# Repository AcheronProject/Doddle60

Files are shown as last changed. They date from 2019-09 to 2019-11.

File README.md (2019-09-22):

# Acheron ISO60-SM-S-STM32-MX-TH-WI (Codename "Doddle60")

Acheron Logo

See [this page](https://gondolindrim.github.io/AcheronDocs/doddle60/intro.html) for the Doddle60PCB documentation.

## Introduction

**Doddle**. *British slang for something easily accomplished*.

The Doddle60 is a 60% plain-style PCB aimed at ISO layout users. It features minimal layout support and no LED backlight support. It runs an STM32F072 processor, USBC connector, ESD protection on both data lines and metallic case discharge, as well as overvoltage and overcurrent protection.

The layout was cherry-picked and hinited to me by Jae of the TopClack channel, an avid ISO user brit.

## Supported layouts

Click [this link](http://www.keyboard-layout-editor.com/#/gists/dfb069e34f7b14d63b03305a79dfc469) for the KLE file for the Doddle60.

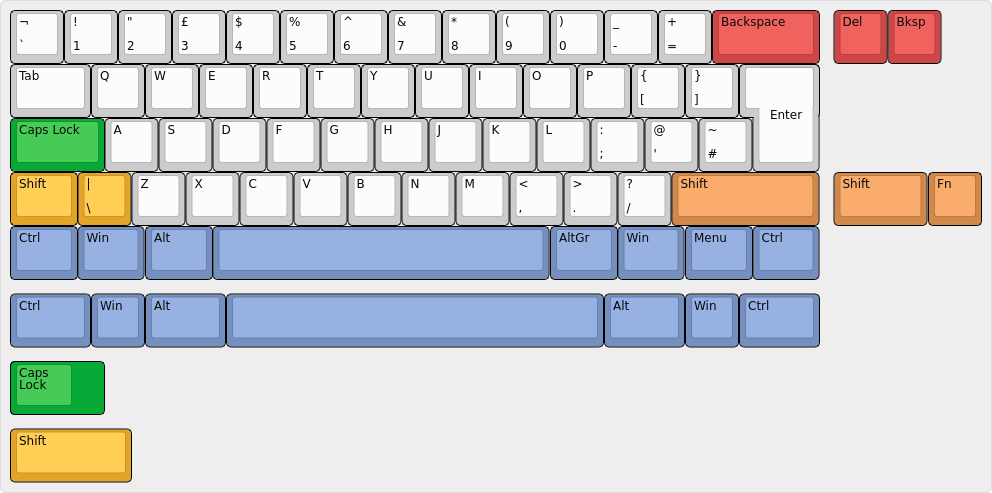
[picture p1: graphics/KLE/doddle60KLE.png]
Austin layouts


## Renders

Click at the images to zoom in.

Renders generated by the [tracespace.io](https://tracespace.io/view/) site.

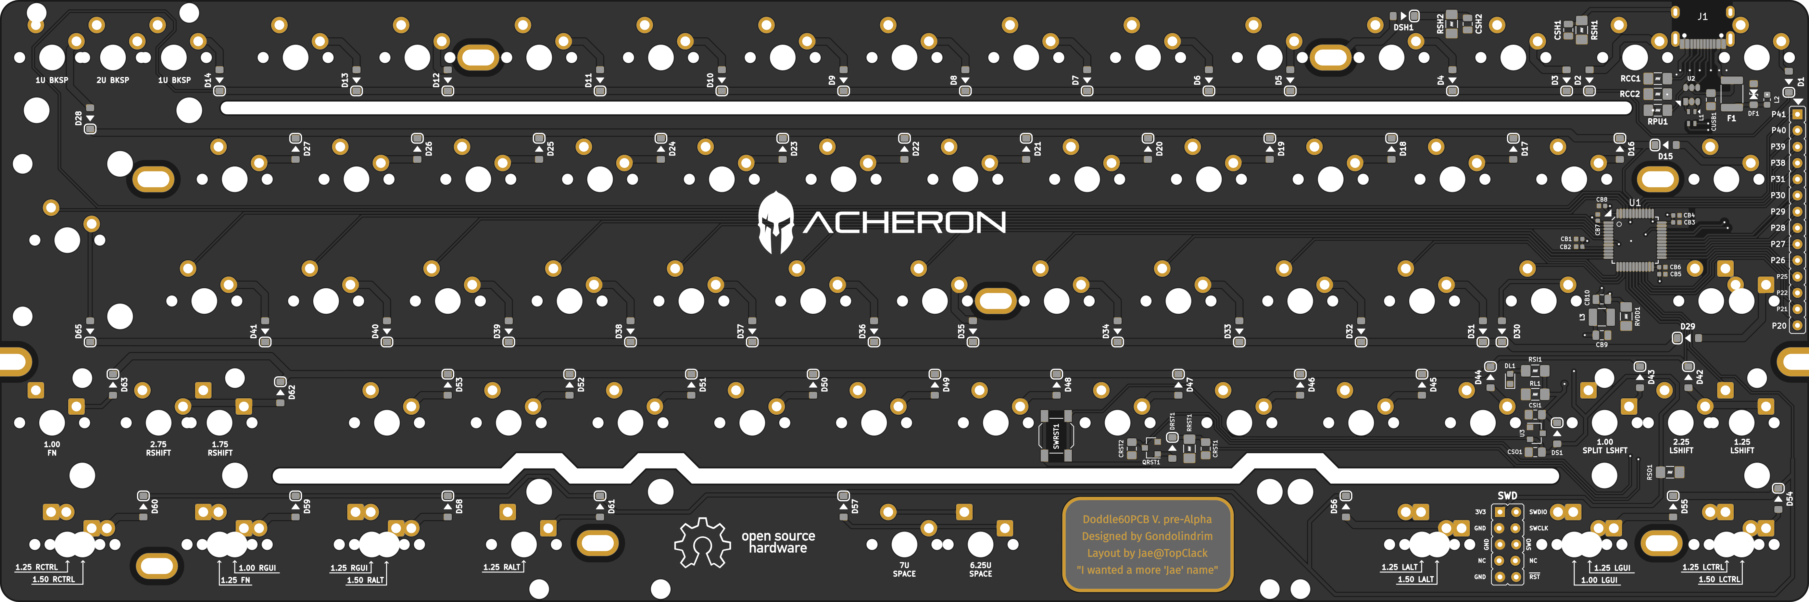
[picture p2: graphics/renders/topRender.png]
ArcticPCB Top Render


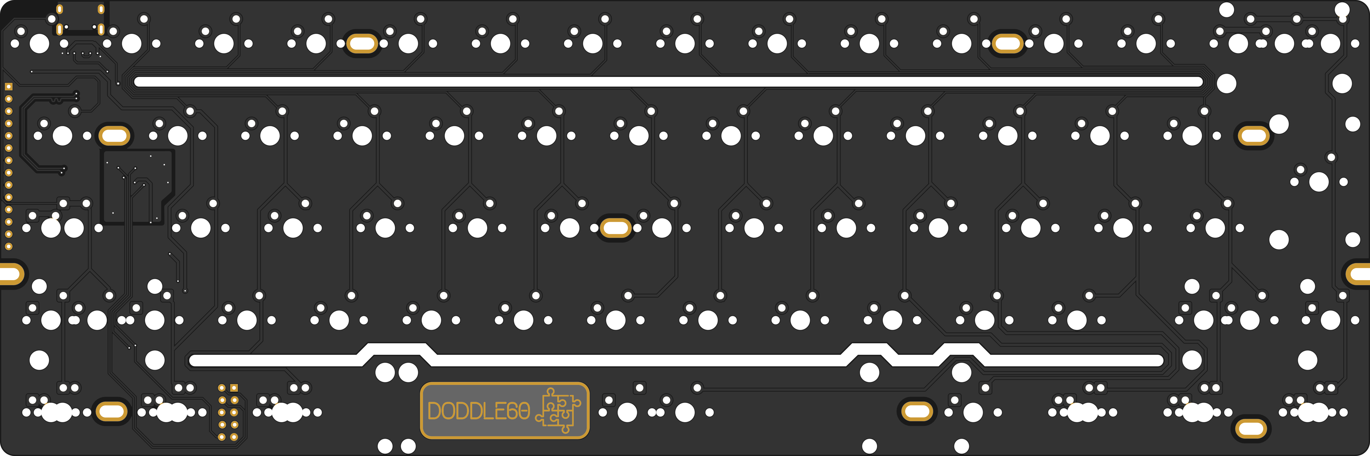
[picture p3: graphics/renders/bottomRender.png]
ArcticPCB Bottom Render


## Copyright notice

This project is released under the Acheron Open-Hardware License V1.1. For the license, please refer to the LICENCE.md file.

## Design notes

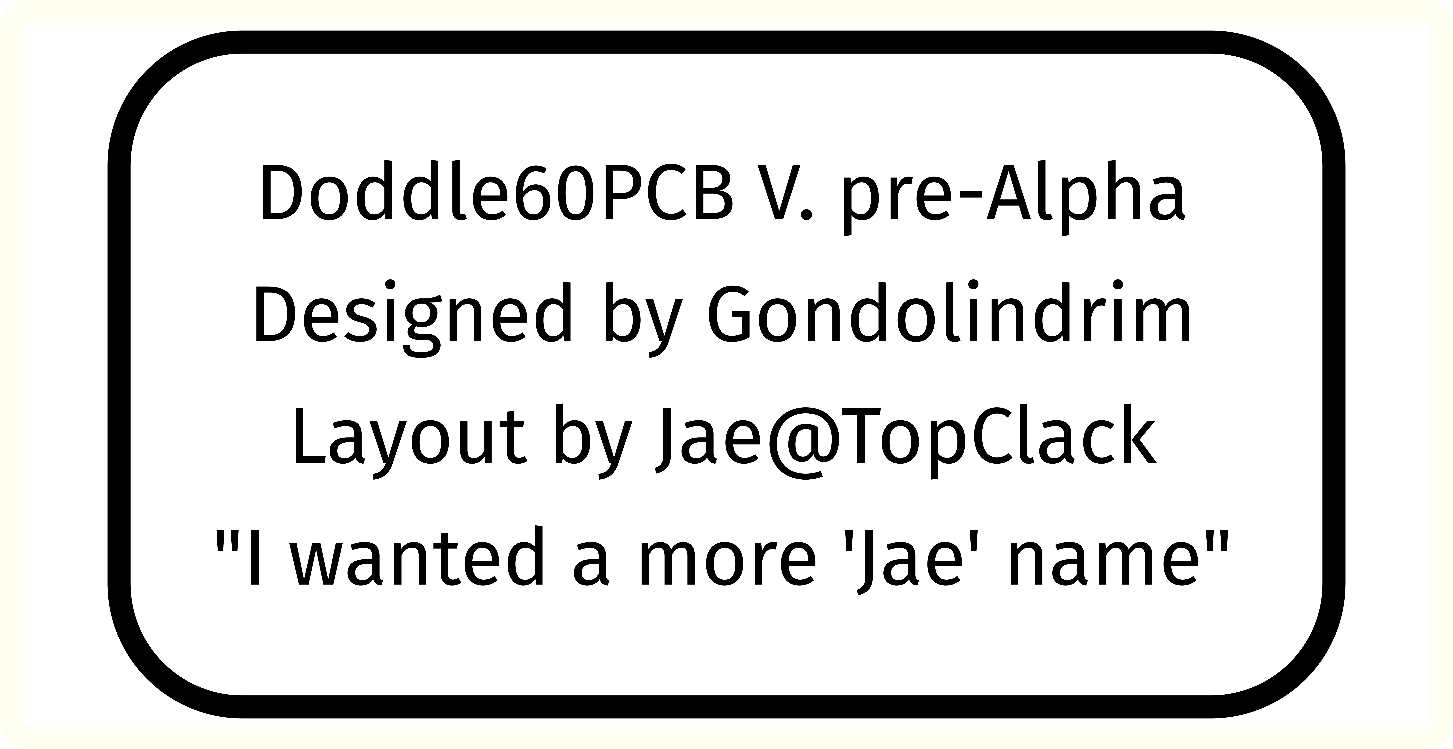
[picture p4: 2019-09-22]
graphics/doddle60Label/doddle60Label.png

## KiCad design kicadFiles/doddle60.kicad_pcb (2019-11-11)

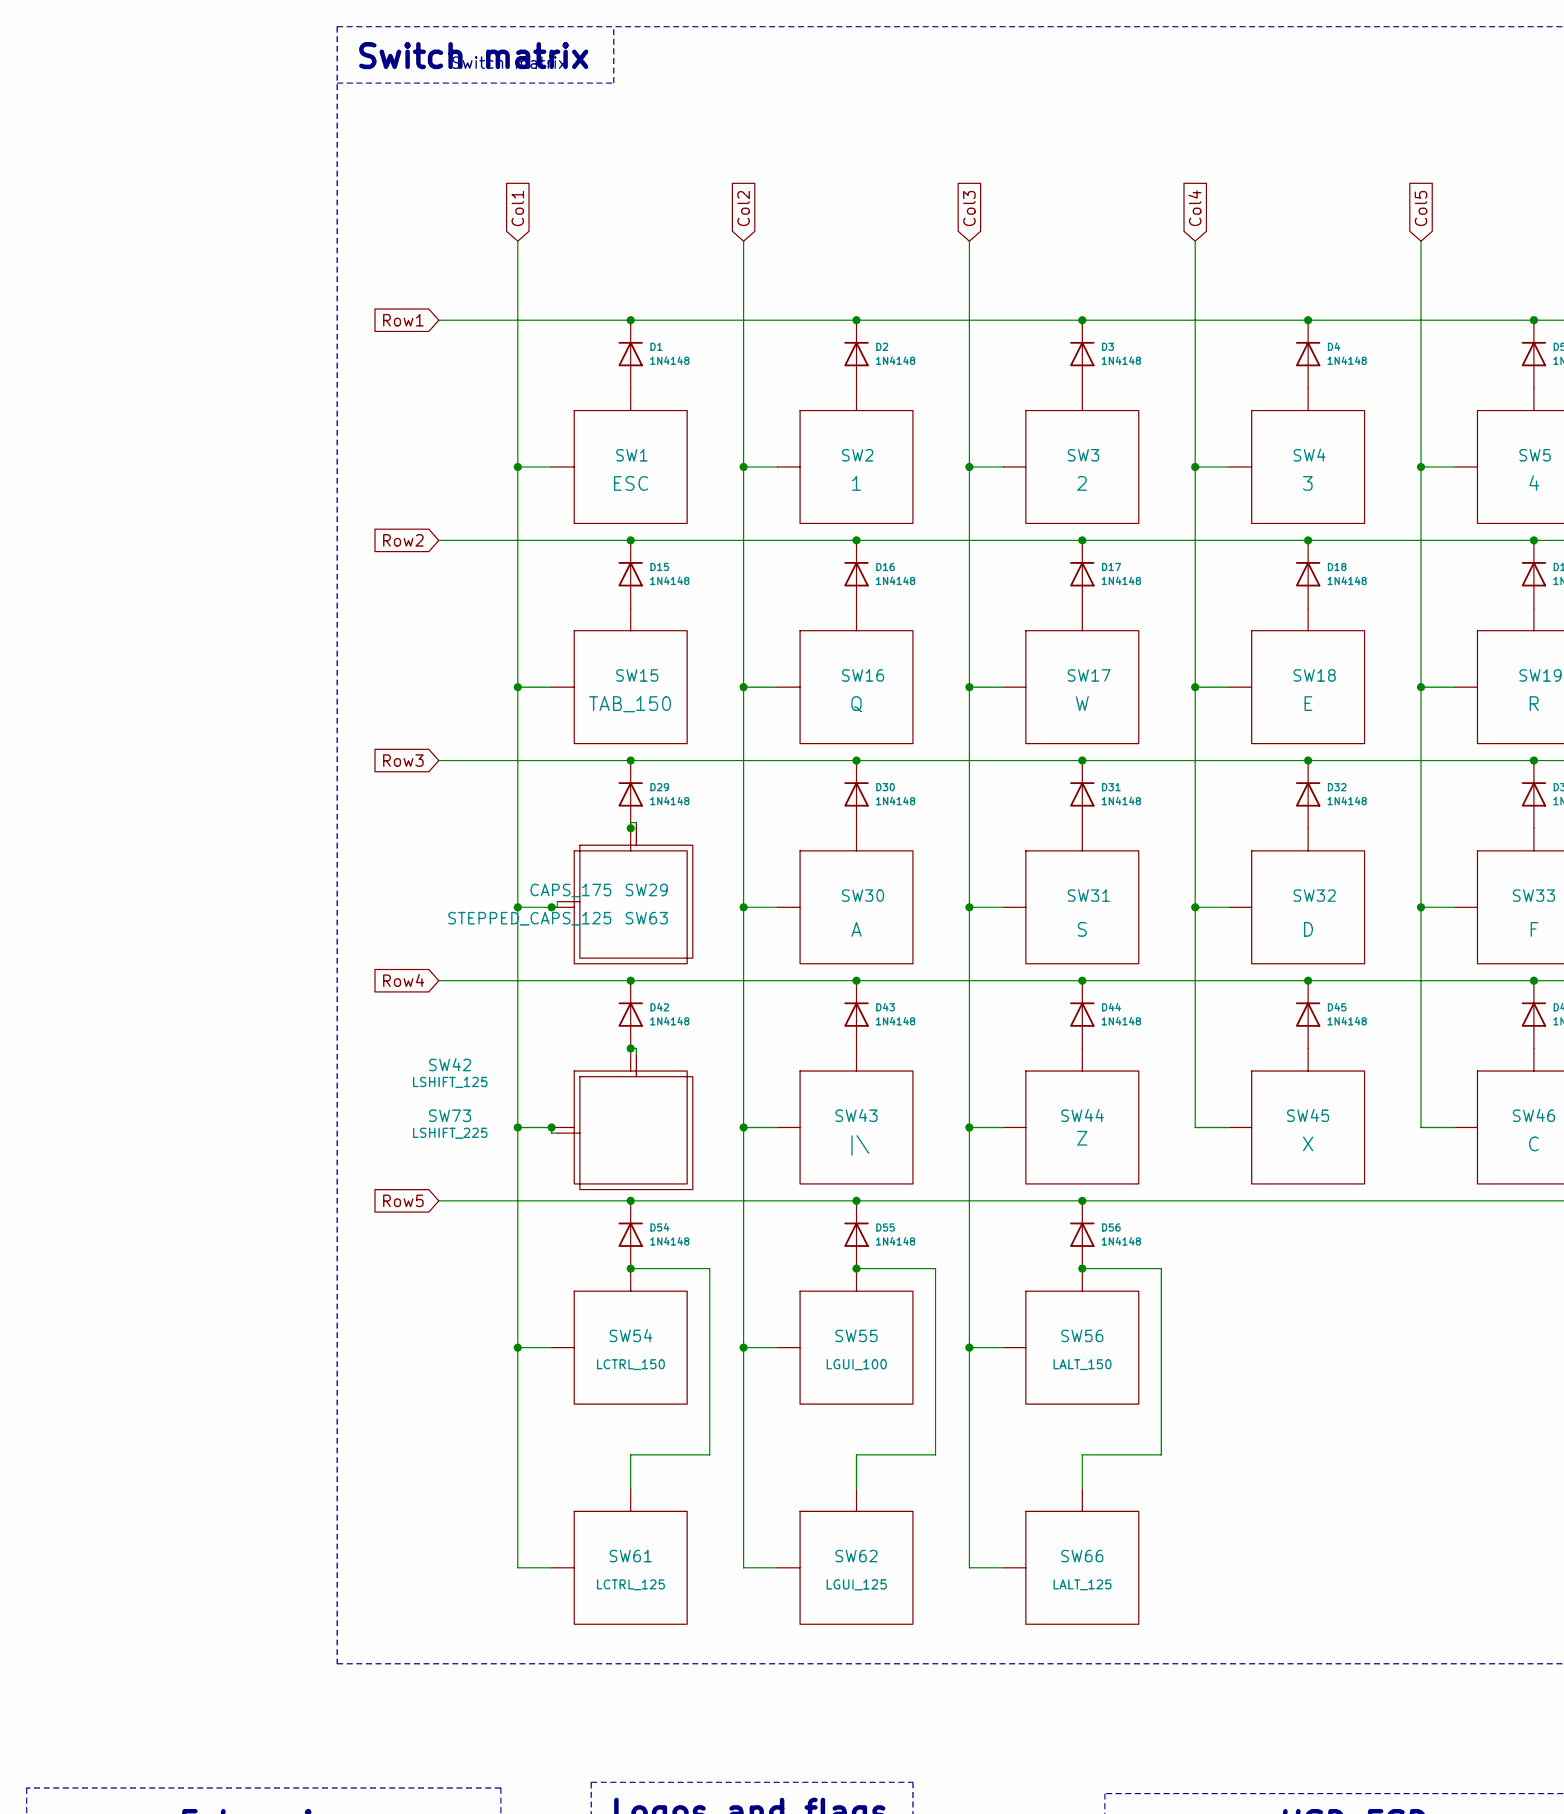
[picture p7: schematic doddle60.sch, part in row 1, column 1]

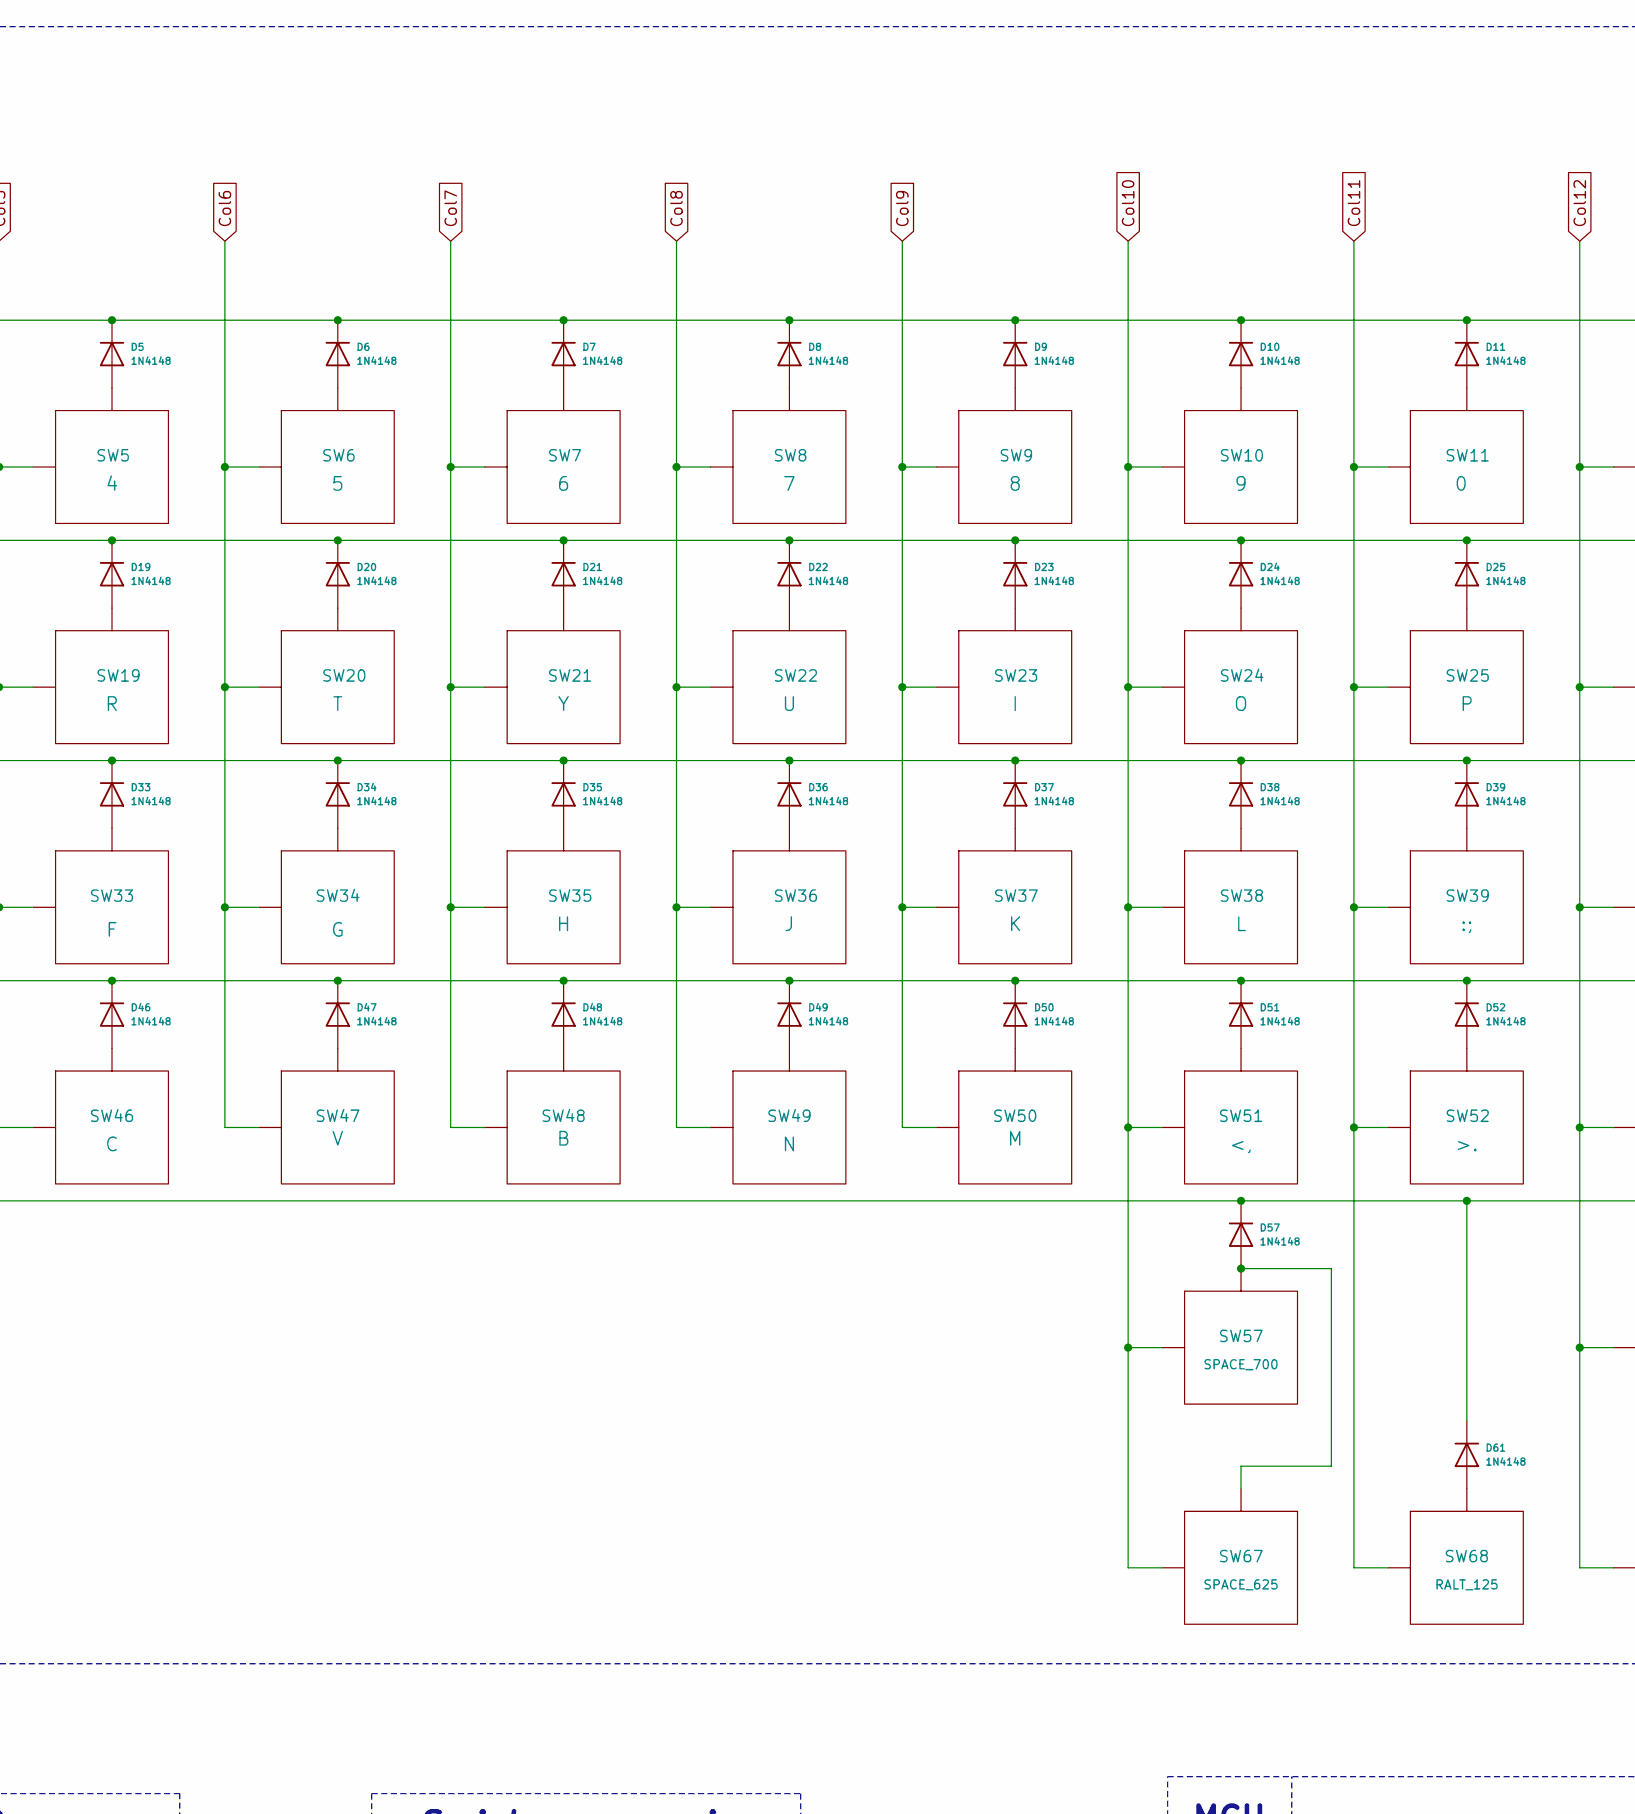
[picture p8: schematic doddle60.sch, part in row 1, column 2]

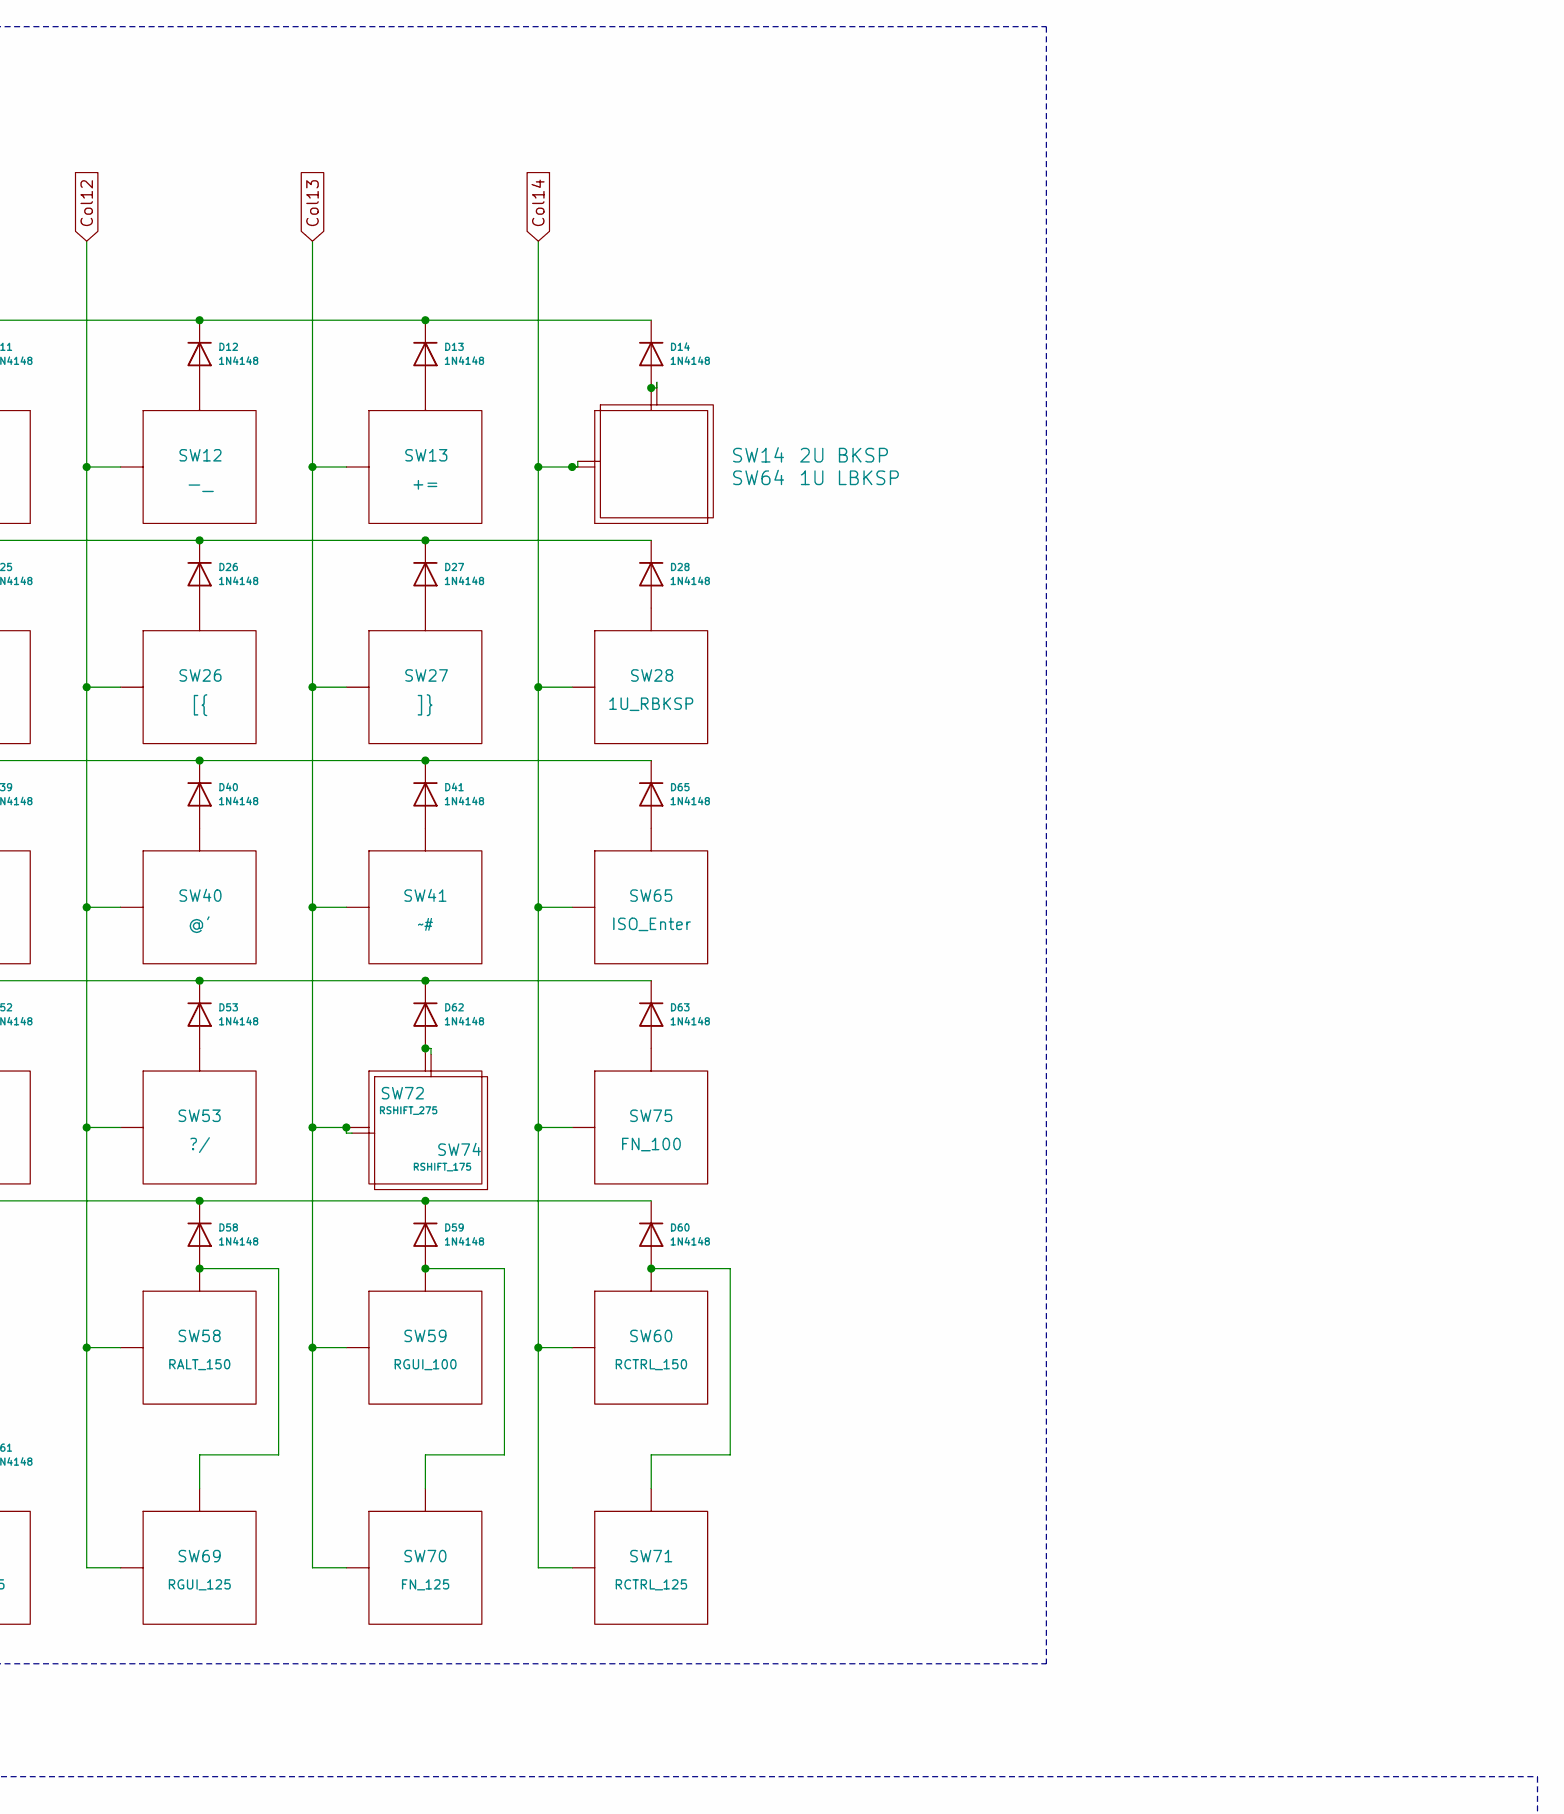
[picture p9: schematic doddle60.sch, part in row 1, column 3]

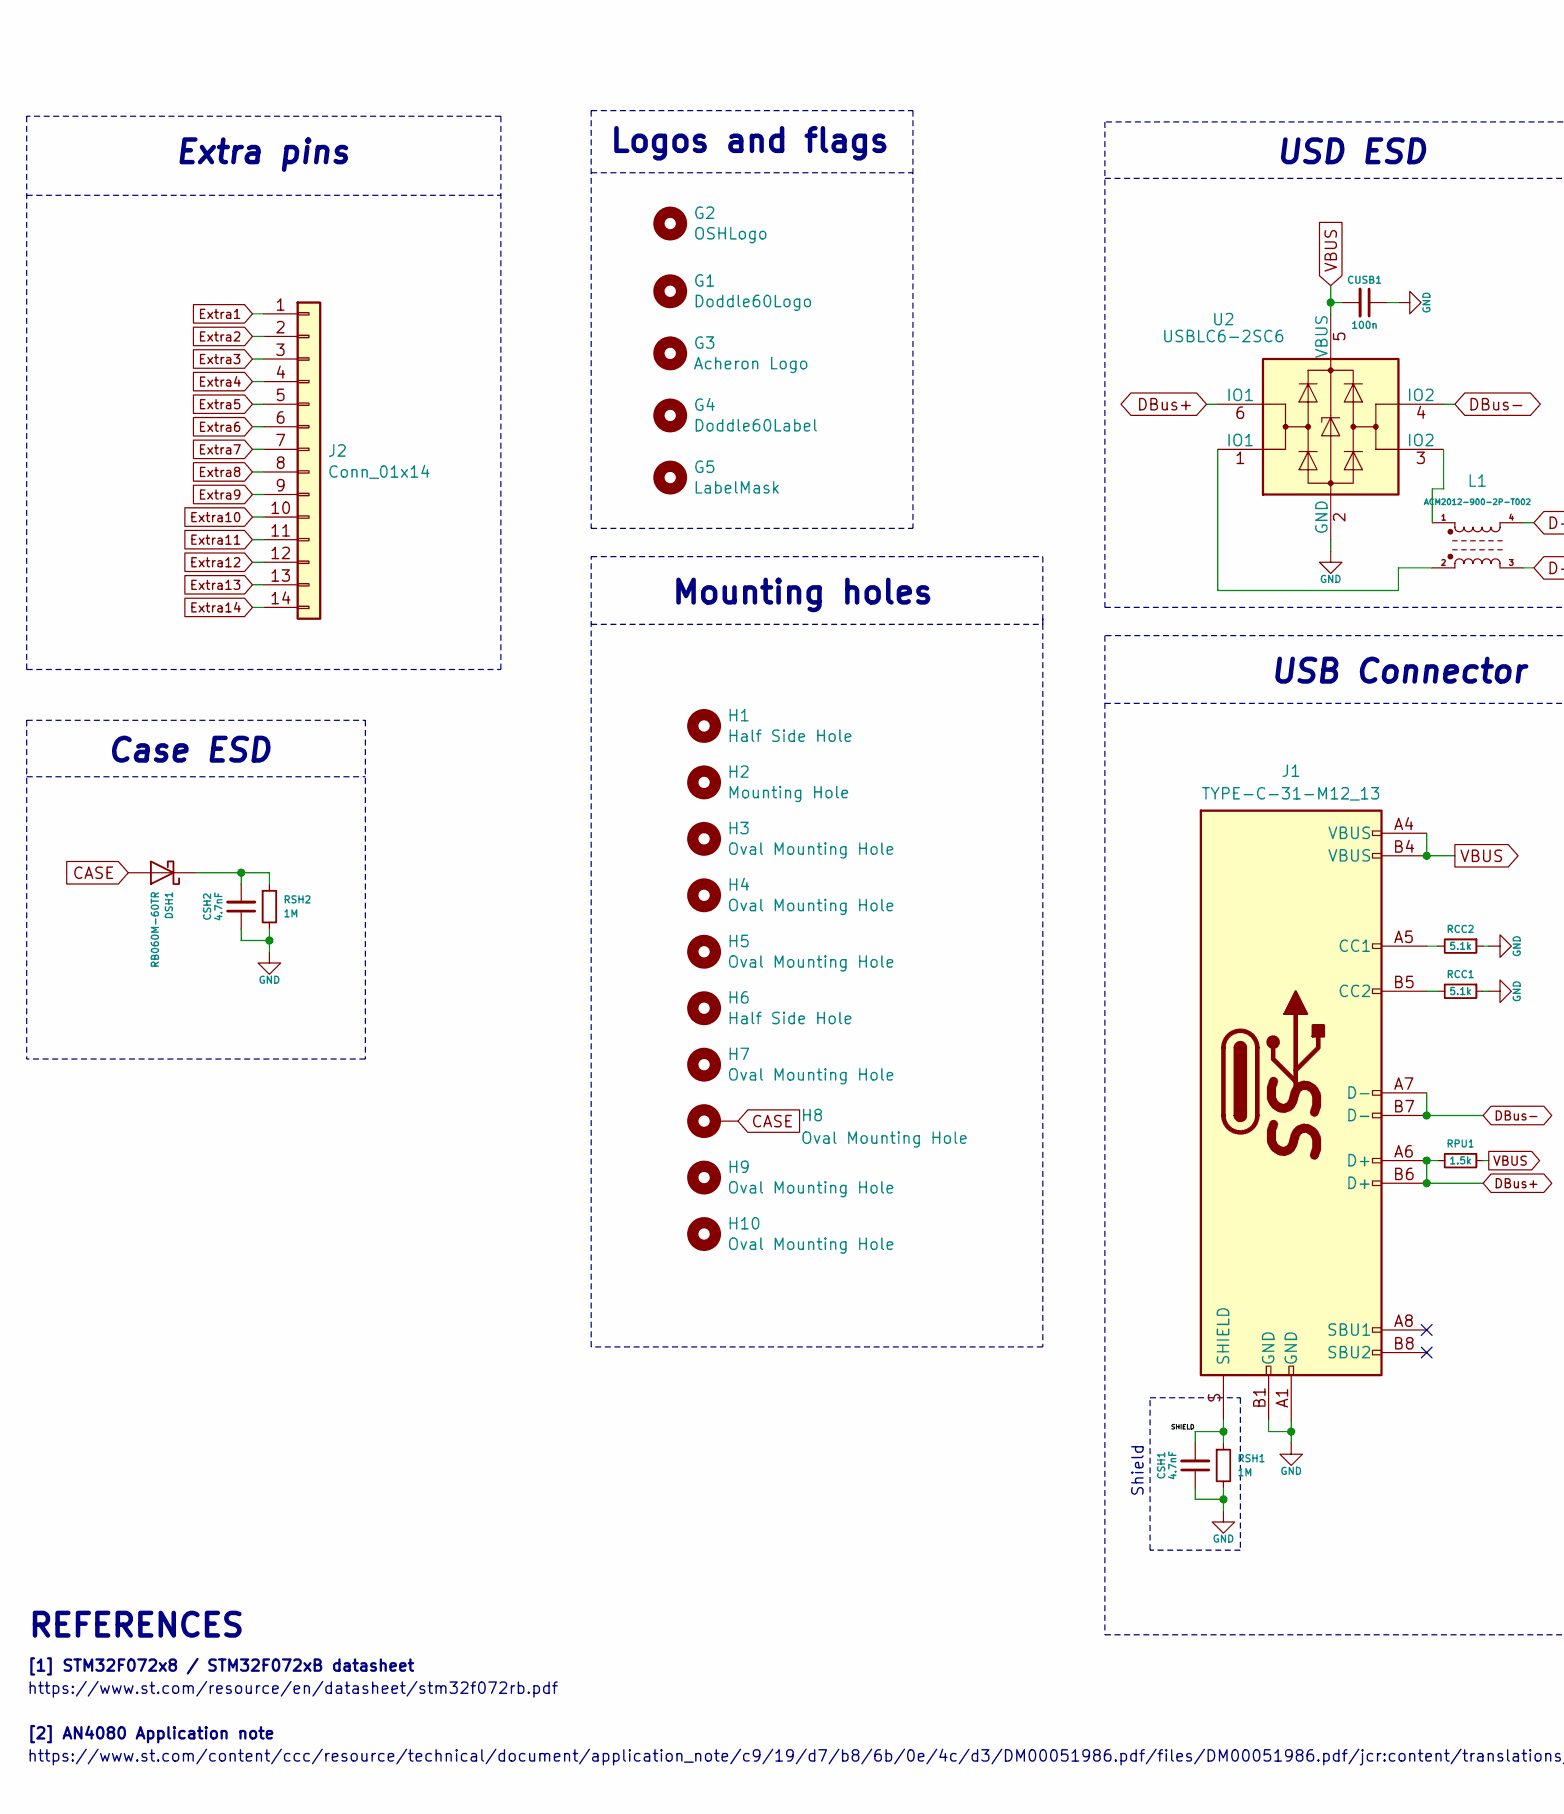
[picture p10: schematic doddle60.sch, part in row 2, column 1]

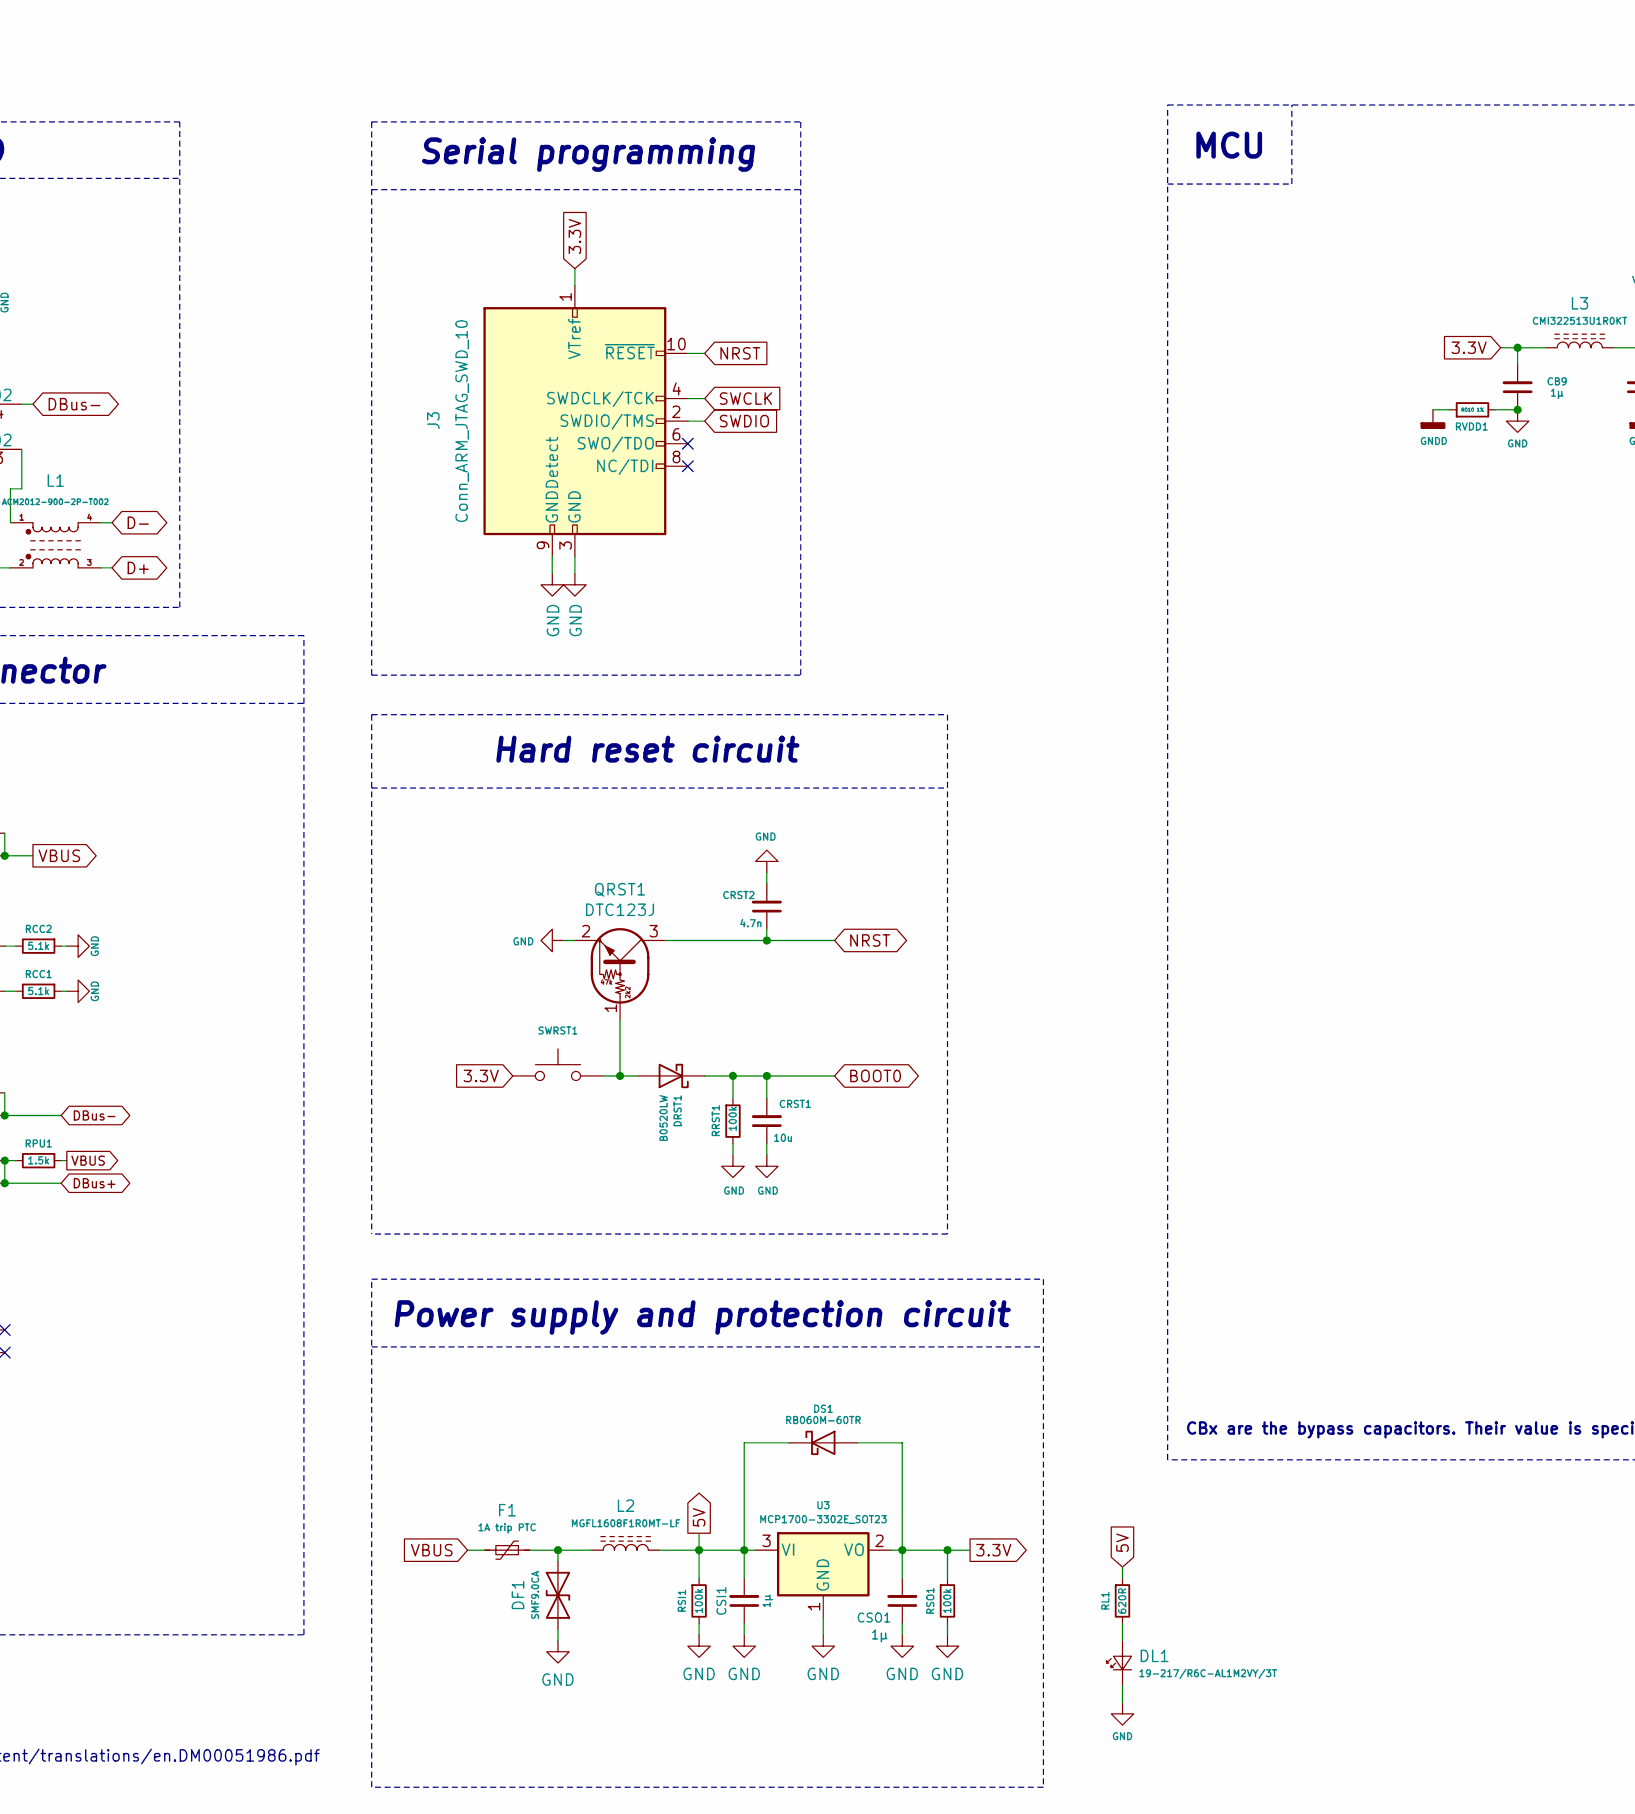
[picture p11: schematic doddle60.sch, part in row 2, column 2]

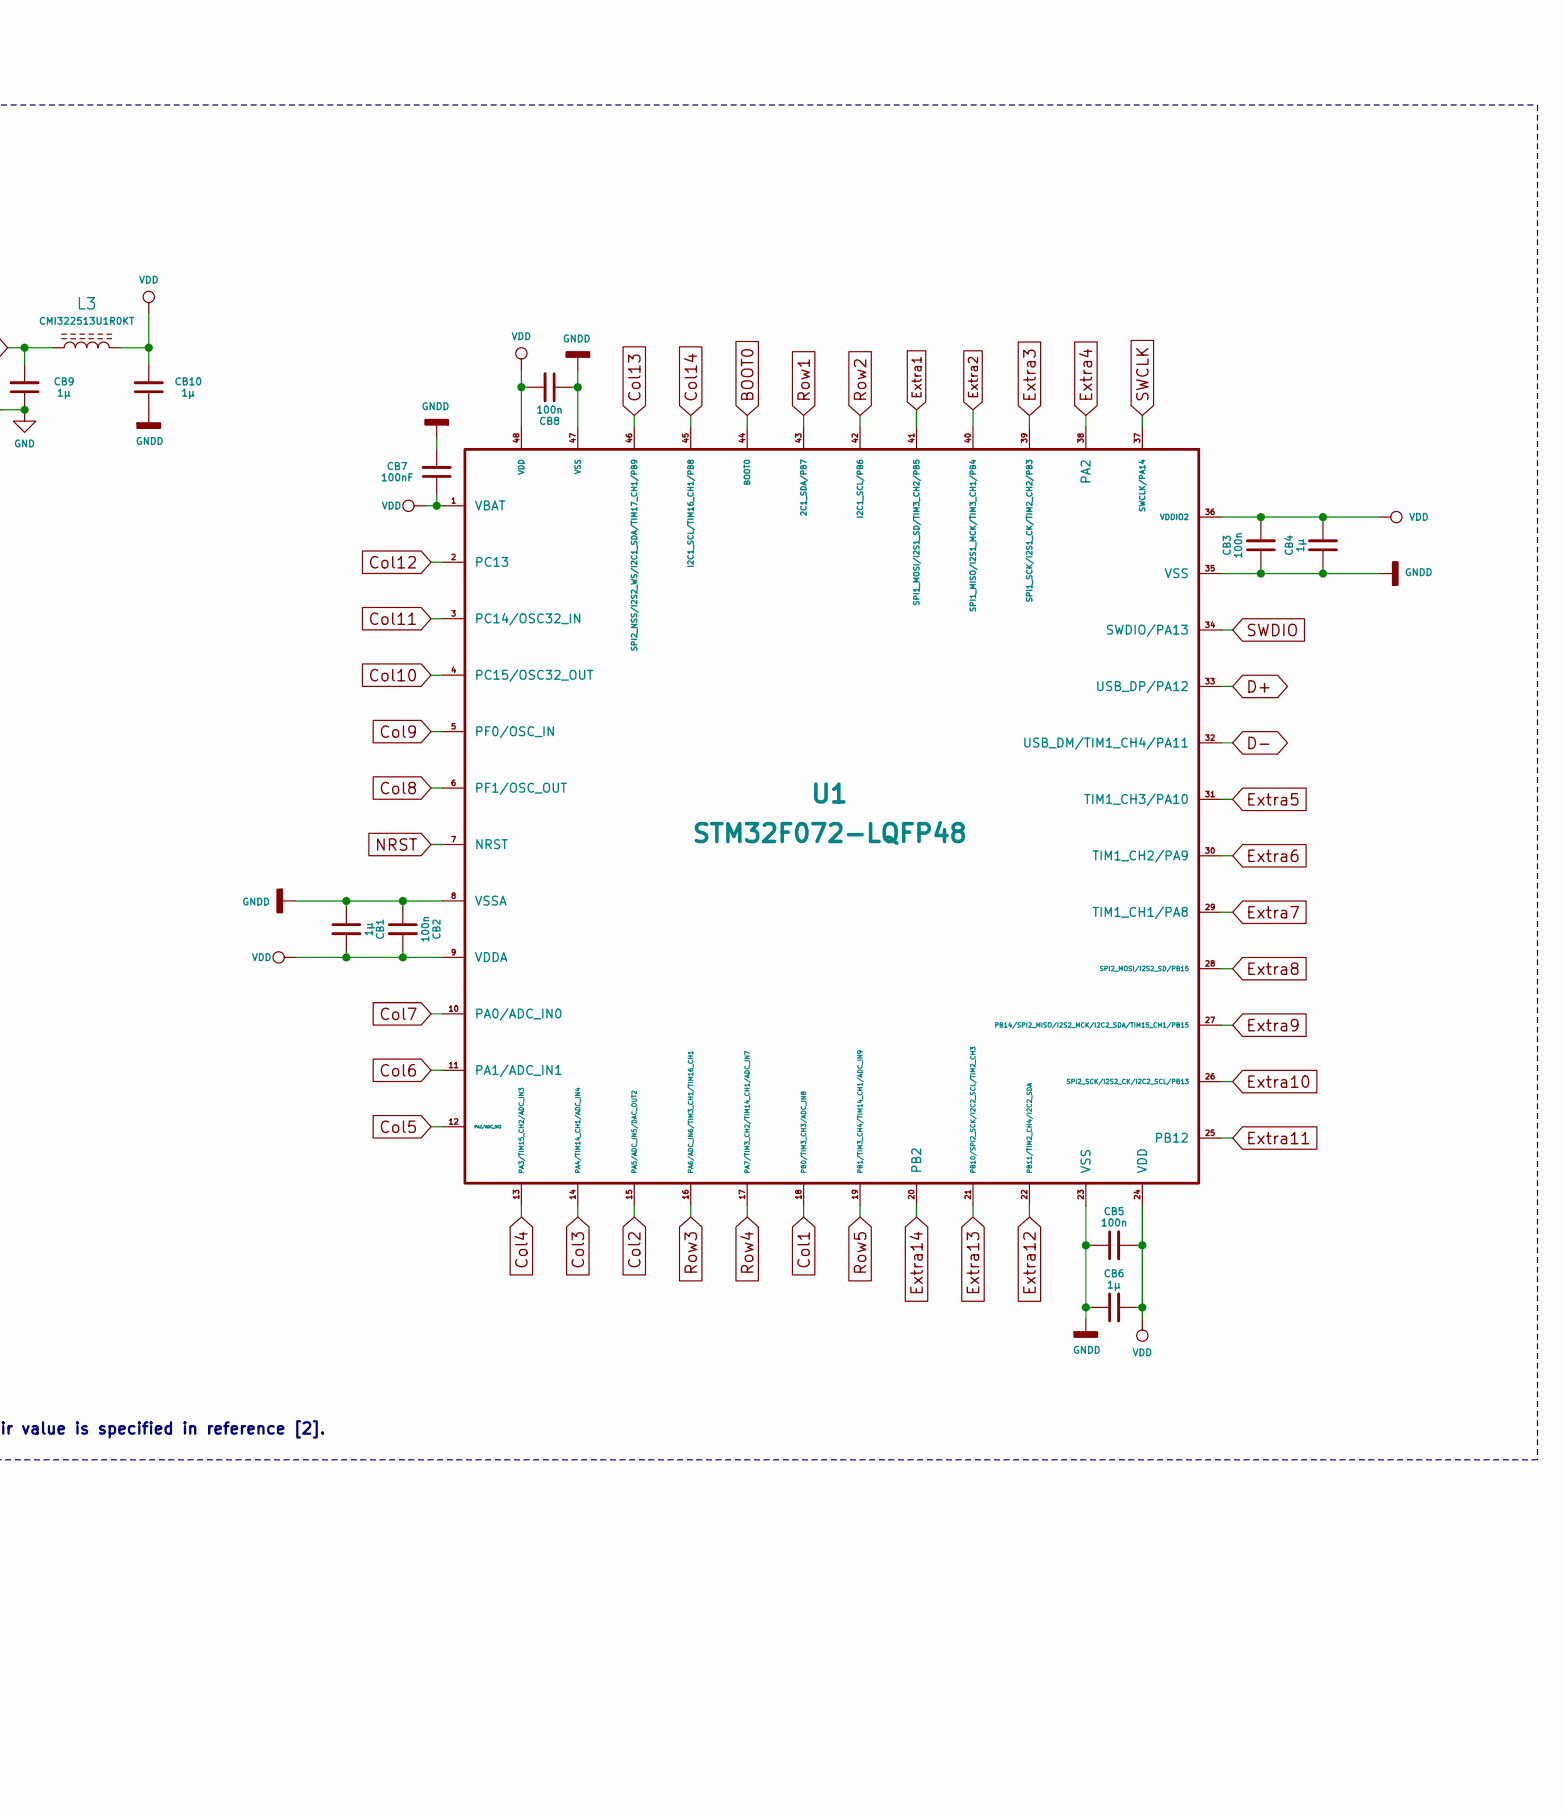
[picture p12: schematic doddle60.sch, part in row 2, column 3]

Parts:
CB1, CB4, CB6: 1µ; C_0402_1005Metric
CB2, CB3, CB5, CB8: 100n; C_0402_1005Metric
CB7: 100nF; C_0402_1005Metric
CB9, CB10: 1µ; C_0805_2012Metric
CRST1: 10u; C_0805_2012Metric_Pad1.15x1.40mm_HandSolder
CRST2: 4.7n; C_0805_2012Metric_Pad1.15x1.40mm_HandSolder
CSH1, CSH2: 4.7nF; C_0805_2012Metric
CSI1: 1µ; C_0805_2012Metric_Pad1.15x1.40mm_HandSolder
CSO1: 1µ; C_0805_2012Metric_Pad1.15x1.40mm_HandSolder
CUSB1: 100n; C_0805_2012Metric_Pad1.15x1.40mm_HandSolder
D1, D2, D3, D4, D5, D6, D7, D8, D9, D10, D11, D12, D13, D14, D15, D16, D17, D18, D19, D20, D21, D22, D23, D24, D25, D26, D27, D28, D29, D30, D31, D32, D33, D34, D35, D36, D37, D38, D39, D40, D41, D42, D43, D44, D45, D46, D47, D48, D49, D50, D51, D52, D53, D54, D55, D56, D57, D58, D59, D60, D61, D62, D63, D65: 1N4148; D_SOD-123
DF1: SMF9.0CA; D_SOD-123_Bidirectional
DL1: 19-217/R6C-AL1M2VY/3T; LED_0603_1608Metric
DRST1: B0520LW; D_SOD-123
DS1: RB060M-60TR; D_SOD-123
DSH1: RB060M-60TR; D_SOD-123
F1: 1A trip PTC; Fuse_1812_4532
G1: Doddle60Logo; doddle60Logo
G2: OSHLogo; osh-logo
G3: Acheron Logo; acheronLong
G4: Doddle60Label; doddle60Label
G5: LabelMask; doddle60LabelMask
H1, H6: Half Side Hole; halfSideHole
H2: Mounting Hole; MoutingHole_Oval_7mm_5.0x2.5mm
H3, H4, H5, H7, H8, H9, H10: Oval Mounting Hole; MoutingHole_Oval_7mm_5.0x2.5mm
J1: TYPE-C-31-M12_13; TYPE-C-31-M-12
J2: Conn_01x14; PinHeader_1x14_P2.54mm_Vertical
J3: Conn_ARM_JTAG_SWD_10
L1: ACM2012-900-2P-T002; ACM2012-2P
L2: MGFL1608F1R0MT-LF; L_0603_1608Metric
L3: CMI322513U1R0KT; L_1210_3225Metric
QRST1: DTC123J; SOT-23
RCC1, RCC2: 5.1k; R_SMD_1026
RL1: 620R; R_SMD_1026
RPU1: 1.5k; R_SMD_1026
RRST1: 100k; R_SMD_1026
RSH1, RSH2: 1M; R_SMD_1026
RSI1: 100k; R_SMD_1026
RSO1: 100k; R_SMD_1026
RVDD1: R010 1%; R_SMD_1026
SW1: ESC; MX100
SW2: 1; MX100
SW3: 2; MX100
SW4: 3; MX100
SW5: 4; MX100
SW6: 5; MX100
SW7: 6; MX100
SW8: 7; MX100
SW9: 8; MX100
SW10: 9; MX100
SW11: 0; MX100
SW12: -_; MX100
SW13: +=; MX100
SW14: 2U BKSP; MX200
SW15: TAB_150; MX150
SW16: Q; MX100
SW17: W; MX100
SW18: E; MX100
SW19: R; MX100
SW20: T; MX100
SW21: Y; MX100
SW22: U; MX100
SW23: I; MX100
SW24: O; MX100
SW25: P; MX100
SW26: [{; MX100
SW27: ]}; MX100
SW28: 1U_RBKSP; MX100
SW29: CAPS_175; MX175
SW30: A; MX100
SW31: S; MX100
SW32: D; MX100
SW33: F; MX100
SW34: G; MX100
SW35: H; MX100
SW36: J; MX100
SW37: K; MX100
SW38: L; MX100
SW39: :;; MX100
SW40: @'; MX100
SW41: ~~#; MX100
SW42: LSHIFT_125; MX125
SW43: |\\; MX100
SW44: Z; MX100
SW45: X; MX100
SW46: C; MX100
SW47: V; MX100
SW48: B; MX100
SW49: N; MX100
SW50: M; MX100
SW51: <,; MX100
SW52: >.; MX100
SW53: ?/; MX100
SW54: LCTRL_150; MX150
SW55: LGUI_100; MX100
SW56: LALT_150; MX150
SW57: SPACE_700; MX700R
SW58: RALT_150; MX150
SW59: RGUI_100; MX100
SW60: RCTRL_150; MX150
SW61: LCTRL_125; MX125
SW62: LGUI_125; MX125
SW63: STEPPED_CAPS_125; MX125
SW64: 1U LBKSP; MX100
SW65: ISO_Enter; MX_ISOEnter_Vertical
SW66: LALT_125; MX125
SW67: SPACE_625; MX625R
SW68: RALT_125; MX125
SW69: RGUI_125; MX125
SW70: FN_125; MX125
SW71: RCTRL_125; MX125
SW72: RSHIFT_275; MX275
SW73: LSHIFT_225; MX225
SW74: RSHIFT_175; MX175
SW75: FN_100; MX100
SWRST1: SW_Push; smdPushBtn
U1: STM32F072-LQFP48; LQFP-48_7x7mm_P0.5mm
U2: USBLC6-2SC6; SOT-23-6
U3: MCP1700-3302E_SOT23; SOT-23

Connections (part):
3.3V: CB9.2, CSO1.2, DS1.2 (A), J3.1 (VTref), L3.1, RSO1.1, SWRST1.1, U3.2 (VO)
5V: CSI1.2, DS1.1 (K), L2.2, RL1.1, RSI1.1, U3.3 (VI)
/SHIELD: CSH1.2, J1.S (SHIELD), RSH1.1
BOOT0: CRST1.2, DRST1.1 (K), RRST1.1, U1.44 (BOOT0)
CASE: DSH1.2 (A), H8.1
Col1: SW1.1 (Col), SW15.1 (Col), SW29.1 (Col), SW42.1 (Col), SW54.1 (Col), SW61.1 (Col), SW63.1 (Col), SW73.1 (Col), U1.18 (PB0/TIM3_CH3/ADC_IN8)
Col2: SW2.1 (Col), SW16.1 (Col), SW30.1 (Col), SW43.1 (Col), SW55.1 (Col), SW62.1 (Col), U1.15 (PA5/ADC_IN5/DAC_OUT2)
Col3: SW3.1 (Col), SW17.1 (Col), SW31.1 (Col), SW44.1 (Col), SW56.1 (Col), SW66.1 (Col), U1.14 (PA4/TIM14_CH1/ADC_IN4)
Col4: SW4.1 (Col), SW18.1 (Col), SW32.1 (Col), SW45.1 (Col), U1.13 (PA3/TIM15_CH2/ADC_IN3)
Col5: SW5.1 (Col), SW19.1 (Col), SW33.1 (Col), SW46.1 (Col), U1.12 (PA2/ADC_IN2)
Col6: SW6.1 (Col), SW20.1 (Col), SW34.1 (Col), SW47.1 (Col), U1.11 (PA1/ADC_IN1)
Col7: SW7.1 (Col), SW21.1 (Col), SW35.1 (Col), SW48.1 (Col), U1.10 (PA0/ADC_IN0)
Col8: SW8.1 (Col), SW22.1 (Col), SW36.1 (Col), SW49.1 (Col), U1.6 (PF1/OSC_OUT)
Col9: SW9.1 (Col), SW23.1 (Col), SW37.1 (Col), SW50.1 (Col), U1.5 (PF0/OSC_IN)
Col10: SW10.1 (Col), SW24.1 (Col), SW38.1 (Col), SW51.1 (Col), SW57.1 (Col), SW67.1 (Col), U1.4 (PC15/OSC32_OUT)
Col11: SW11.1 (Col), SW25.1 (Col), SW39.1 (Col), SW52.1 (Col), SW68.1 (Col), U1.3 (PC14/OSC32_IN)
Col12: SW12.1 (Col), SW26.1 (Col), SW40.1 (Col), SW53.1 (Col), SW58.1 (Col), SW69.1 (Col), U1.2 (PC13)
Col13: SW13.1 (Col), SW27.1 (Col), SW41.1 (Col), SW59.1 (Col), SW70.1 (Col), SW72.1 (Col), SW74.1 (Col), U1.46 (SPI2_NSS/I2S2_WS/I2C1_SDA/TIM17_CH1/PB9)
Col14: SW14.1 (Col), SW28.1 (Col), SW60.1 (Col), SW64.1 (Col), SW65.1 (Col), SW71.1 (Col), SW75.1 (Col), U1.45 (I2C1_SCL/TIM16_CH1/PB8)
D+: L1.3, U1.33 (USB_DP/PA12)
D-: L1.4, U1.32 (USB_DM/TIM1_CH4/PA11)
DBus+: J1.A6 (D+), J1.B6 (D+), RPU1.2, U2.6 (IO1)
DBus-: J1.A7 (D-), J1.B7 (D-), U2.4 (IO2)
Extra1: J2.1, U1.41 (SPI1_MOSI/I2S1_SD/TIM3_CH2/PB5)
Extra2: J2.2, U1.40 (SPI1_MISO/I2S1_MCK/TIM3_CH1/PB4)
Extra3: J2.3, U1.39 (SPI1_SCK/I2S1_CK/TIM2_CH2/PB3)
Extra4: J2.4, U1.38 (PA2)
Extra5: J2.5, U1.31 (TIM1_CH3/PA10)
Extra6: J2.6, U1.30 (TIM1_CH2/PA9)
Extra7: J2.7, U1.29 (TIM1_CH1/PA8)
Extra8: J2.8, U1.28 (SPI2_MOSI/I2S2_SD/PB15)
Extra9: J2.9, U1.27 (PB14/SPI2_MISO/I2S2_MCK/I2C2_SDA/TIM15_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)
Extra10: J2.10, U1.26 (SPI2_SCK/I2S2_CK/I2C2_SCL/PB13)
Extra11: J2.11, U1.25 (PB12)
Extra12: J2.12, U1.22 (PB11/TIM2_CH4/I2C2_SDA)
Extra13: J2.13, U1.21 (PB10/SPI2_SCK/I2C2_SCL/TIM2_CH3)
Extra14: J2.14, U1.20 (PB2)
GND: CB9.1, CRST1.1, CRST2.2, CSH1.1, CSH2.1, CSI1.1, CSO1.1, CUSB1.1, DF1.2 (A2), DL1.1 (K), J1.A1 (GND), J1.B1 (GND), J3.3 (GND), J3.5 (GND), J3.9 (GNDDetect), QRST1.2 (E), RCC1.1, RCC2.1, RRST1.2, RSH1.2, RSH2.2, RSI1.2, RSO1.2, RVDD1.2, U2.2 (GND), U3.1 (GND)
GNDD: CB1.1, CB2.1, CB3.1, CB4.1, CB5.1, CB6.1, CB7.2, CB8.1, CB10.1, RVDD1.1, U1.8 (VSSA), U1.23 (VSS), U1.35 (VSS), U1.47 (VSS)
NRST: CRST2.1, J3.10 (~RESET~), QRST1.3 (C), U1.7 (NRST)
unnamed: CSH2.2, DSH1.1 (K), RSH2.1
unnamed: D1.2 (A), SW1.2 (Row)
unnamed: D2.2 (A), SW2.2 (Row)
unnamed: D3.2 (A), SW3.2 (Row)
unnamed: D4.2 (A), SW4.2 (Row)
unnamed: D5.2 (A), SW5.2 (Row)
unnamed: D6.2 (A), SW6.2 (Row)
unnamed: D7.2 (A), SW7.2 (Row)
unnamed: D8.2 (A), SW8.2 (Row)
unnamed: D9.2 (A), SW9.2 (Row)
unnamed: D10.2 (A), SW10.2 (Row)
unnamed: D11.2 (A), SW11.2 (Row)
unnamed: D12.2 (A), SW12.2 (Row)
unnamed: D13.2 (A), SW13.2 (Row)
unnamed: D14.2 (A), SW14.2 (Row), SW64.2 (Row)
unnamed: D15.2 (A), SW15.2 (Row)
unnamed: D16.2 (A), SW16.2 (Row)
unnamed: D17.2 (A), SW17.2 (Row)
unnamed: D18.2 (A), SW18.2 (Row)
unnamed: D19.2 (A), SW19.2 (Row)
unnamed: D20.2 (A), SW20.2 (Row)
unnamed: D21.2 (A), SW21.2 (Row)
unnamed: D22.2 (A), SW22.2 (Row)
unnamed: D23.2 (A), SW23.2 (Row)
unnamed: D24.2 (A), SW24.2 (Row)
unnamed: D25.2 (A), SW25.2 (Row)
unnamed: D26.2 (A), SW26.2 (Row)
unnamed: D27.2 (A), SW27.2 (Row)
unnamed: D28.2 (A), SW28.2 (Row)
unnamed: D29.2 (A), SW29.2 (Row), SW63.2 (Row)
unnamed: D30.2 (A), SW30.2 (Row)
unnamed: D31.2 (A), SW31.2 (Row)
unnamed: D32.2 (A), SW32.2 (Row)
unnamed: D33.2 (A), SW33.2 (Row)
unnamed: D34.2 (A), SW34.2 (Row)
unnamed: D35.2 (A), SW35.2 (Row)
unnamed: D36.2 (A), SW36.2 (Row)
unnamed: D37.2 (A), SW37.2 (Row)
unnamed: D38.2 (A), SW38.2 (Row)
unnamed: D39.2 (A), SW39.2 (Row)
unnamed: D40.2 (A), SW40.2 (Row)
unnamed: D41.2 (A), SW41.2 (Row)
unnamed: D42.2 (A), SW42.2 (Row), SW73.2 (Row)
unnamed: D43.2 (A), SW43.2 (Row)
unnamed: D44.2 (A), SW44.2 (Row)
unnamed: D45.2 (A), SW45.2 (Row)
unnamed: D46.2 (A), SW46.2 (Row)
unnamed: D47.2 (A), SW47.2 (Row)
unnamed: D48.2 (A), SW48.2 (Row)
unnamed: D49.2 (A), SW49.2 (Row)
unnamed: D50.2 (A), SW50.2 (Row)
unnamed: D51.2 (A), SW51.2 (Row)
unnamed: D52.2 (A), SW52.2 (Row)
unnamed: D53.2 (A), SW53.2 (Row)
unnamed: D54.2 (A), SW54.2 (Row), SW61.2 (Row)
unnamed: D55.2 (A), SW55.2 (Row), SW62.2 (Row)
unnamed: D56.2 (A), SW56.2 (Row), SW66.2 (Row)
unnamed: D57.2 (A), SW57.2 (Row), SW67.2 (Row)
unnamed: D58.2 (A), SW58.2 (Row), SW69.2 (Row)
unnamed: D59.2 (A), SW59.2 (Row), SW70.2 (Row)
unnamed: D60.2 (A), SW60.2 (Row), SW71.2 (Row)
unnamed: D61.2 (A), SW68.2 (Row)
unnamed: D62.2 (A), SW72.2 (Row), SW74.2 (Row)
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

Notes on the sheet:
Hard reset circuit
Power supply and protection circuit
Logos and flags
Serial programming
[1] STM32F072x8 / STM32F072xB datasheet
REFERENCES
https://www.st.com/resource/en/datasheet/stm32f072rb.pdf
[2] AN4080 Application note
https://www.st.com/content/ccc/resource/technical/document/application_note/c9/19/d7/b8/6b/0e/4c/d3/DM00051986.pdf/files/DM00051986.pdf/jcr:content/translations/en.D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
MCU
USB Connector
Shield
USD ESD
CBx are the bypass capacitors. Their value is specified in reference [2].
Case ESD
Switch matrix
Mounting holes
Extra pins

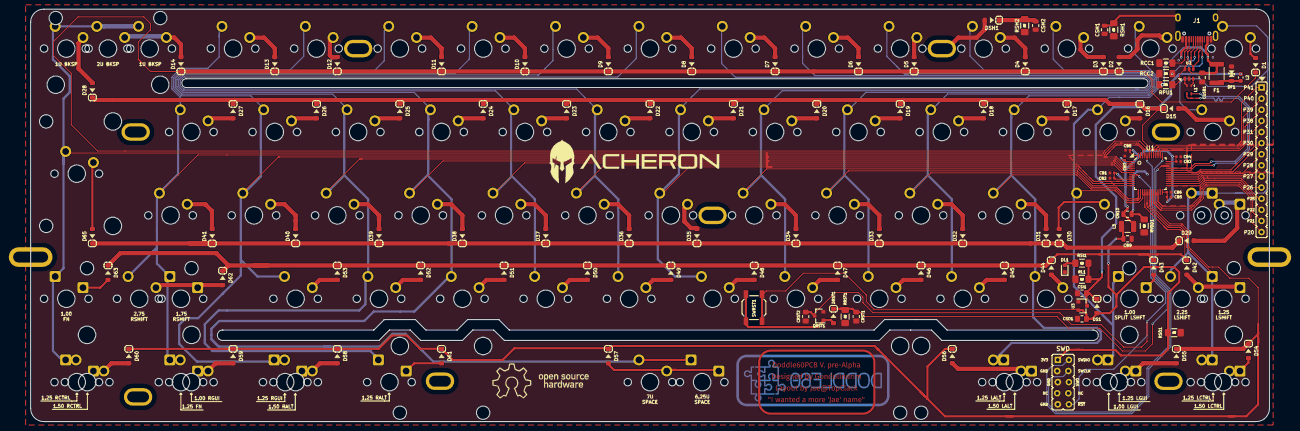
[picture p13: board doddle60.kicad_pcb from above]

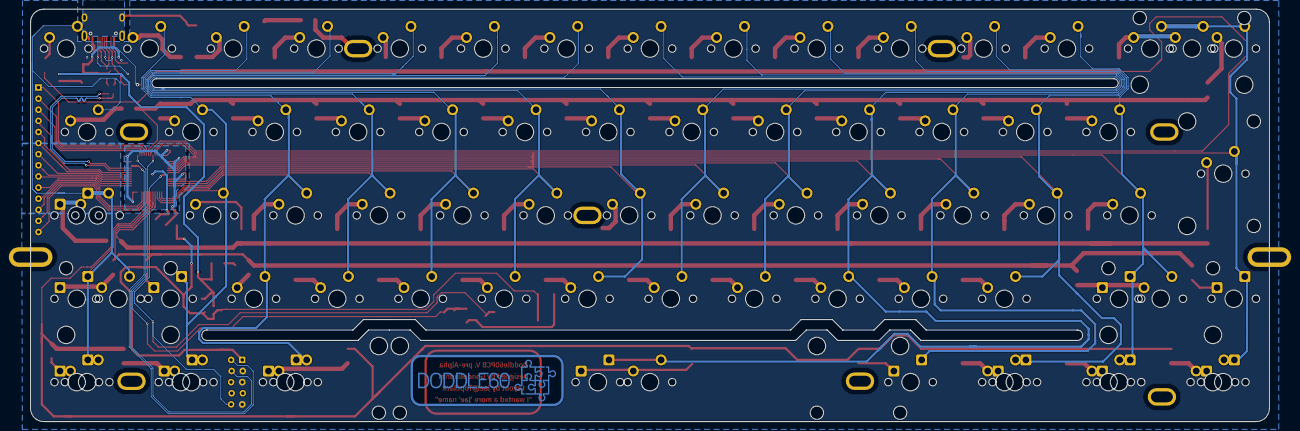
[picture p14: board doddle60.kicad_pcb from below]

Board: 2 copper layers, 283.0 x 94.2 mm, 198 parts (7 on the bottom side), 121 nets.

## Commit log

2019-10-25 Incorporate feedback from GeekHack IC
    - There was a big feedback from the community on the GeekHack Interest Check thread (https://geekhack.org/index.php?topic=103057), mainly the lack of split right shift conpatibility and 2.25 left shi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
    - Some tweaks were made in the LDO area. Input and output resistors were added to discharge all the capacitors once the PCB is not energized. Also the value os CSO1 was changed from 100nF to 1uF for 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
    [doddle60.kicad_pcb, doddle60.sch]
2019-10-25 Run DRC
    - DRC was ran and issues solved
    [doddle60.kicad_pcb]
2019-10-25 Update KLE and renders
    [doddle60.kicad_pcb, doddle60.sch]
2019-10-25 Add TVS, diff impedance, pi filter
    - A TVS diode was added to the VBUS power rail for more stability and voltage clamping;
    - A differential mode choke was added to the data lines;
    - A pi filter with a differential mode choke was added to the MCU power circuit for isolation and stability
    [doddle60.sch]
2019-11-05 Implement filters, TVS and LED
    - The pi filter for VDD and GNDD was implemented; the common mode choke
    added to the schematic on the last commit was deemed unnecessary and
    thence removed
    - The TVS and choke for VBUS-5V was implemented;
    - The common mode choke for USB data lines was added
    [doddle60.kicad_pcb, doddle60.sch]
2019-11-05 Add layout indicator silkscreen
    [doddle60.kicad_pcb, doddle60.sch]
2019-11-11 Update renders
    [doddle60.kicad_pcb, doddle60.sch]
